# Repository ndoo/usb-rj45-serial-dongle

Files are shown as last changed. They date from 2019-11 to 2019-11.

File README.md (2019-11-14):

# USB RJ-45 Serial Dongle

A small USB to RS232 serial dongle, presented as a female RJ-45 jack that can be used with your choice of straight-through cable. Pinout is stanard Cisco RJ-45 console. Compatibility may vary with other vendors.

## Motivation

Commercial USB to Cisco-style serial cables are generally a single molded assembly, which means any issues with the RJ-45 jack (such as retention clip breaking) or forceful disconnection such as dropping your laptop, may neccesitate replacing the entire dongle.

By presenting a female RJ-45 jack, you now have the freedom to choose any length and quality of straight-through Ethernet cable, and replace it as clips break.

## Bill of Materials and Ordering

| Designator | MPN | Qty | Link |
|---|---|-----|---|
| C1,C3 | CC0402MRX5R5BB475 | 2 | |
| C2,C4,C5,C6,C7,C8 | CC0402KRX7R8BB104 | 6 | |
| R1 | RC0402FR-071KL | 1 | |
| R2,R3 | RC0402FR-07330RL | 2 | |
| R4 | RC0402FR-0722KL | 1 | |
| R5 | RC0402FR-0747KL | 1 | |
| U1 | CP2102N-A01-GQFN20R | 1 | https://www.digikey.sg/product-detail/en/silicon-labs/CP2102N-A01-GQFN20R/336-4826-1-ND/8619802 |
| U2 | MAX202ECWE+ | 1 | https://www.digikey.sg/product-detail/en/maxim-integrated/MAX202ECWE/MAX202ECWE-ND/947811 |
| U3 | SP0503BAHTG | 1 | https://www.digikey.sg/product-detail/en/littelfuse-inc/SP0503BAHTG/F2715CT-ND/1154322 |
| J1 | RJHSE-5081 | 1 | https://www.digikey.sg/product-detail/en/amphenol-icc-commercial-products/RJHSE-5081/RJHSE-5081-ND/1242688 |

## License

This project is licensed under the MIT License - see the [LICENSE.md](LICENSE.md) file for details

## Acknowledgments

* USB connector is from USBPCB from Sparkfun's EAGLE libraries

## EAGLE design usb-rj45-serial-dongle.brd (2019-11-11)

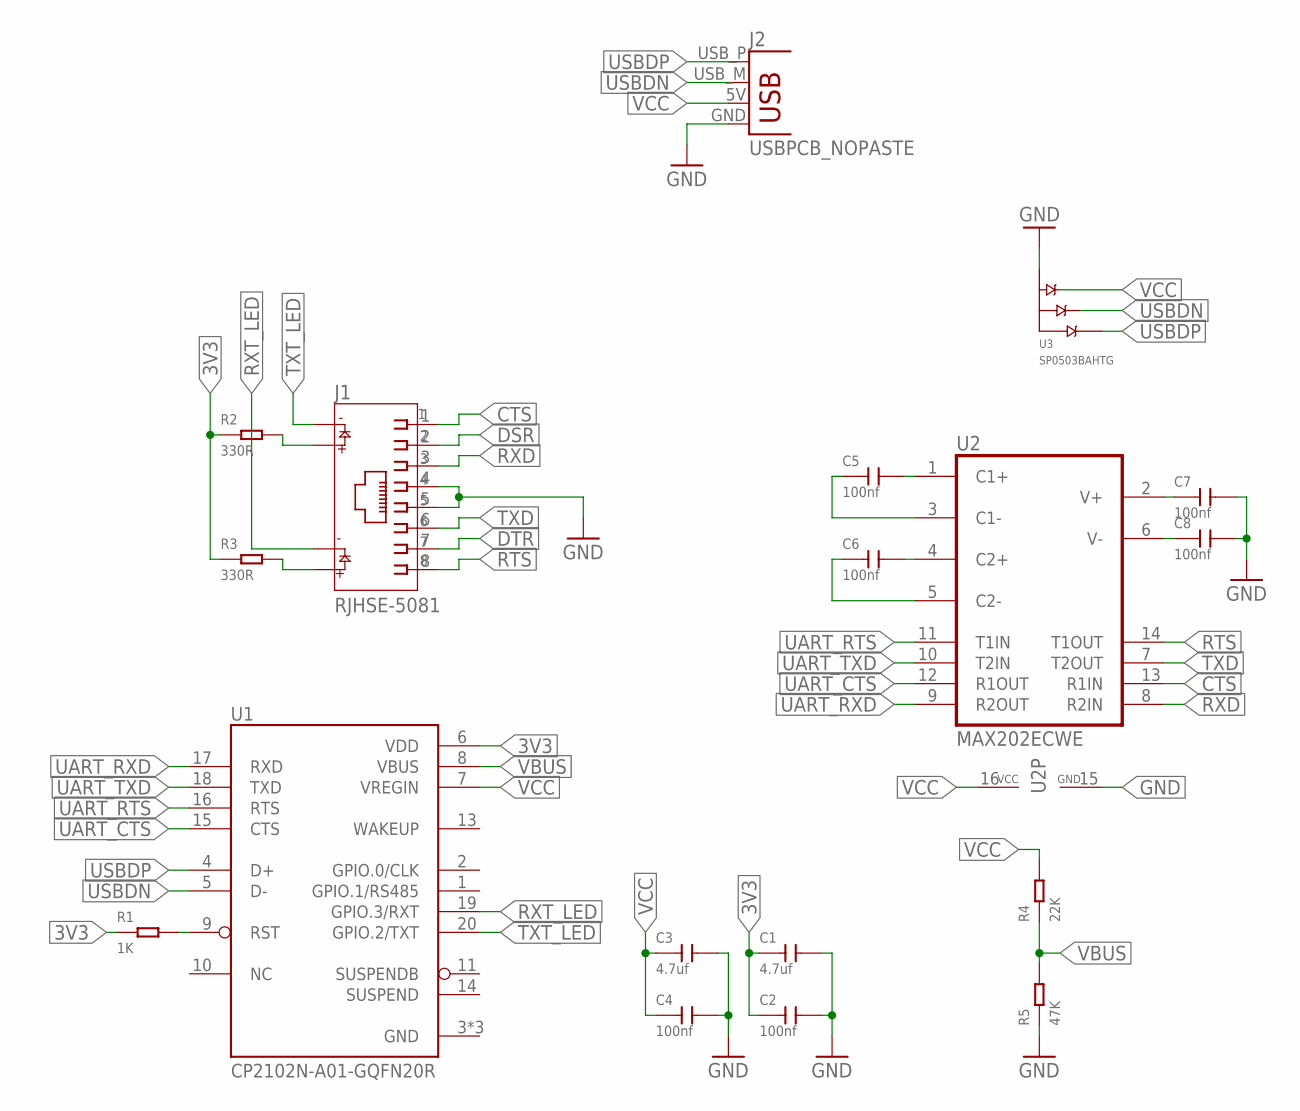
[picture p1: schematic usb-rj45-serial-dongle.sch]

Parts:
C1, C3: 4.7uf; C0402
C2, C4, C5, C6, C7, C8: 100nf; C0402
J1: RJHSE-5081
J2: USBPCB_NOPASTE; USB-A-PCB-NOPASTE
R1: 1K; R0402
R2, R3: 330R; R0402
R4: 22K; R0402
R5: 47K; R0402
U1: CP2102N-A01-GQFN20R; SILABS_QFN20
U2: MAX202ECWE; SO16L
U3: SP0503BAHTG; SOT143

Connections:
3V3: C1.1, C2.1, R1.1, R2.1, R3.1, U1.6 (VDD)
CTS: J1.1, U2.13 (R1IN)
DSR: J1.2
DTR: J1.7
GND: C1.2, C2.2, C3.2, C4.2, C7.2, C8.2, J1.4, J1.5, J2.GND, R5.1, U1.3 (GND), U1.12 (GND), U1.21 (GND), U2.15 (GND), U3.1 (GND)
unnamed: C5.2, U2.1 (C1+)
unnamed: R1.2, U1.9 (RST)
unnamed: J1.12, R3.2
unnamed: C6.2, U2.4 (C2+)
unnamed: J1.10, R2.2
unnamed: C5.1, U2.3 (C1-)
unnamed: C6.1, U2.5 (C2-)
unnamed: C7.1, U2.2 (V+)
unnamed: C8.1, U2.6 (V-)
RTS: J1.8, U2.14 (T1OUT)
RXD: J1.3, U2.8 (R2IN)
RXT_LED: J1.11, U1.19 (GPIO.3/RXT)
TXD: J1.6, U2.7 (T2OUT)
TXT_LED: J1.9, U1.20 (GPIO.2/TXT)
UART_CTS: U1.15 (CTS), U2.12 (R1OUT)
UART_RTS: U1.16 (RTS), U2.11 (T1IN)
UART_RXD: U1.17 (RXD), U2.9 (R2OUT)
UART_TXD: U1.18 (TXD), U2.10 (T2IN)
USBDN: J2.USB_M (D-), U1.5 (D-), U3.3 (B)
USBDP: J2.USB_P (D+), U1.4 (D+), U3.4 (C)
VBUS: R4.1, R5.2, U1.8 (VBUS)
VCC: C3.1, C4.1, J2.5V (VBUS), R4.2, U1.7 (VREGIN), U2.16 (VCC), U3.2 (A)

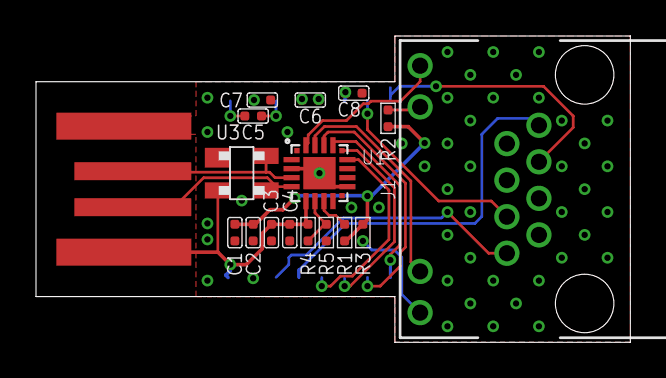
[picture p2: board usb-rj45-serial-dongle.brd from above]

Board: 2 copper layers, 33.0 x 17.0 mm, 18 parts (1 on the bottom side), 25 nets.

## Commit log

2019-11-09 Board updates, silkscreen cleanup and component changes
    Board updates:
    - GND plane stitching changed to a more general pattern rather than closely stitched to signal lines, since we aren't doing RF
    - GND plane optimizations (bottom layer no longer separated into 2 distinct planes)
    - Reduced size of board
    Silkscreen cleanup:
    - Removed values
    - Rotated names and changed size/font to fit better and avoid vias (Seeed Fusion doesn't do blind via silkscreen well)
    Component Changes:
    - J1: RJHSE-5381 (shielded RJ45) replaced with RJHSE-5081 (unshielded RJ45) for smaller footprint and lower cost
    - R3: Changed from Seeed OPL 0402 1KΩ 1% to 5% tolerance part due to value error (0R) on the 1% part
    [usb-rj45-serial-dongle.brd, usb-rj45-serial-dongle.sch]
2019-11-09 Renumber resistors to start from R1
    [usb-rj45-serial-dongle.brd, usb-rj45-serial-dongle.sch]
2019-11-09 Renumber IC1 and other ICs to be in sequence with prefix "U"
    [usb-rj45-serial-dongle.brd, usb-rj45-serial-dongle.sch]
2019-11-09 Add bill of materials
    [Bill of Materials.csv]
2019-11-09 Use CP2102 TXT/RXT pins to drive LEDs, thanks @MatsK for pointing this feature out
    [usb-rj45-serial-dongle.brd, usb-rj45-serial-dongle.sch]
2019-11-11 Add VBUS voltage divider per CP2102N datasheet; Fix CTS/RXD swapped at MAX202E; Routing improvements
    [usb-rj45-serial-dongle.brd, usb-rj45-serial-dongle.sch]
2019-11-11 Review and approve ERC errors/warnings
    [usb-rj45-serial-dongle.sch]
2019-11-14 Update bill of materials with R4 and R5
    [Bill of Materials.csv]

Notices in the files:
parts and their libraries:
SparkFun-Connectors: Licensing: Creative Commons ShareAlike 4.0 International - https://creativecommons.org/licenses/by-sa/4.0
